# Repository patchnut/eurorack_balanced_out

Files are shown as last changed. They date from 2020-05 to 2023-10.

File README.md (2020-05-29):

# Eurorack Balanced Out
Stereo balanced output board with attenuation for in eurorack cases.

This is a Kicad project for a balanced output board to build in the back of an Eurorack case. This is not a eurorack
module, but instead can be built into a eurorack case to provide two balanced outputs on TRS jacks on the back of the case.
The circuit is powered from a normal +12v/-12v eurorack power supply and can be connected to a module that provides
mini-jack connectors so signals can be patched into the output. The current assumption is that we can use the Doepfer A-139-2 
Headphone Amplifier module for this. It provides mini jack inputs, volume control and has two un-populated headers on the board
that look like they provide outputs.

Features
- Two balanced 6,3 mm TRS jack outputs
- 10 pin eurorack compatible power connector for +12v/-12v
- 1/4 attenuation, use different resistors to change attenuation level
- two THAT1646 output drivers
- inputs on two 2-pin headers for internal connection to front panel module

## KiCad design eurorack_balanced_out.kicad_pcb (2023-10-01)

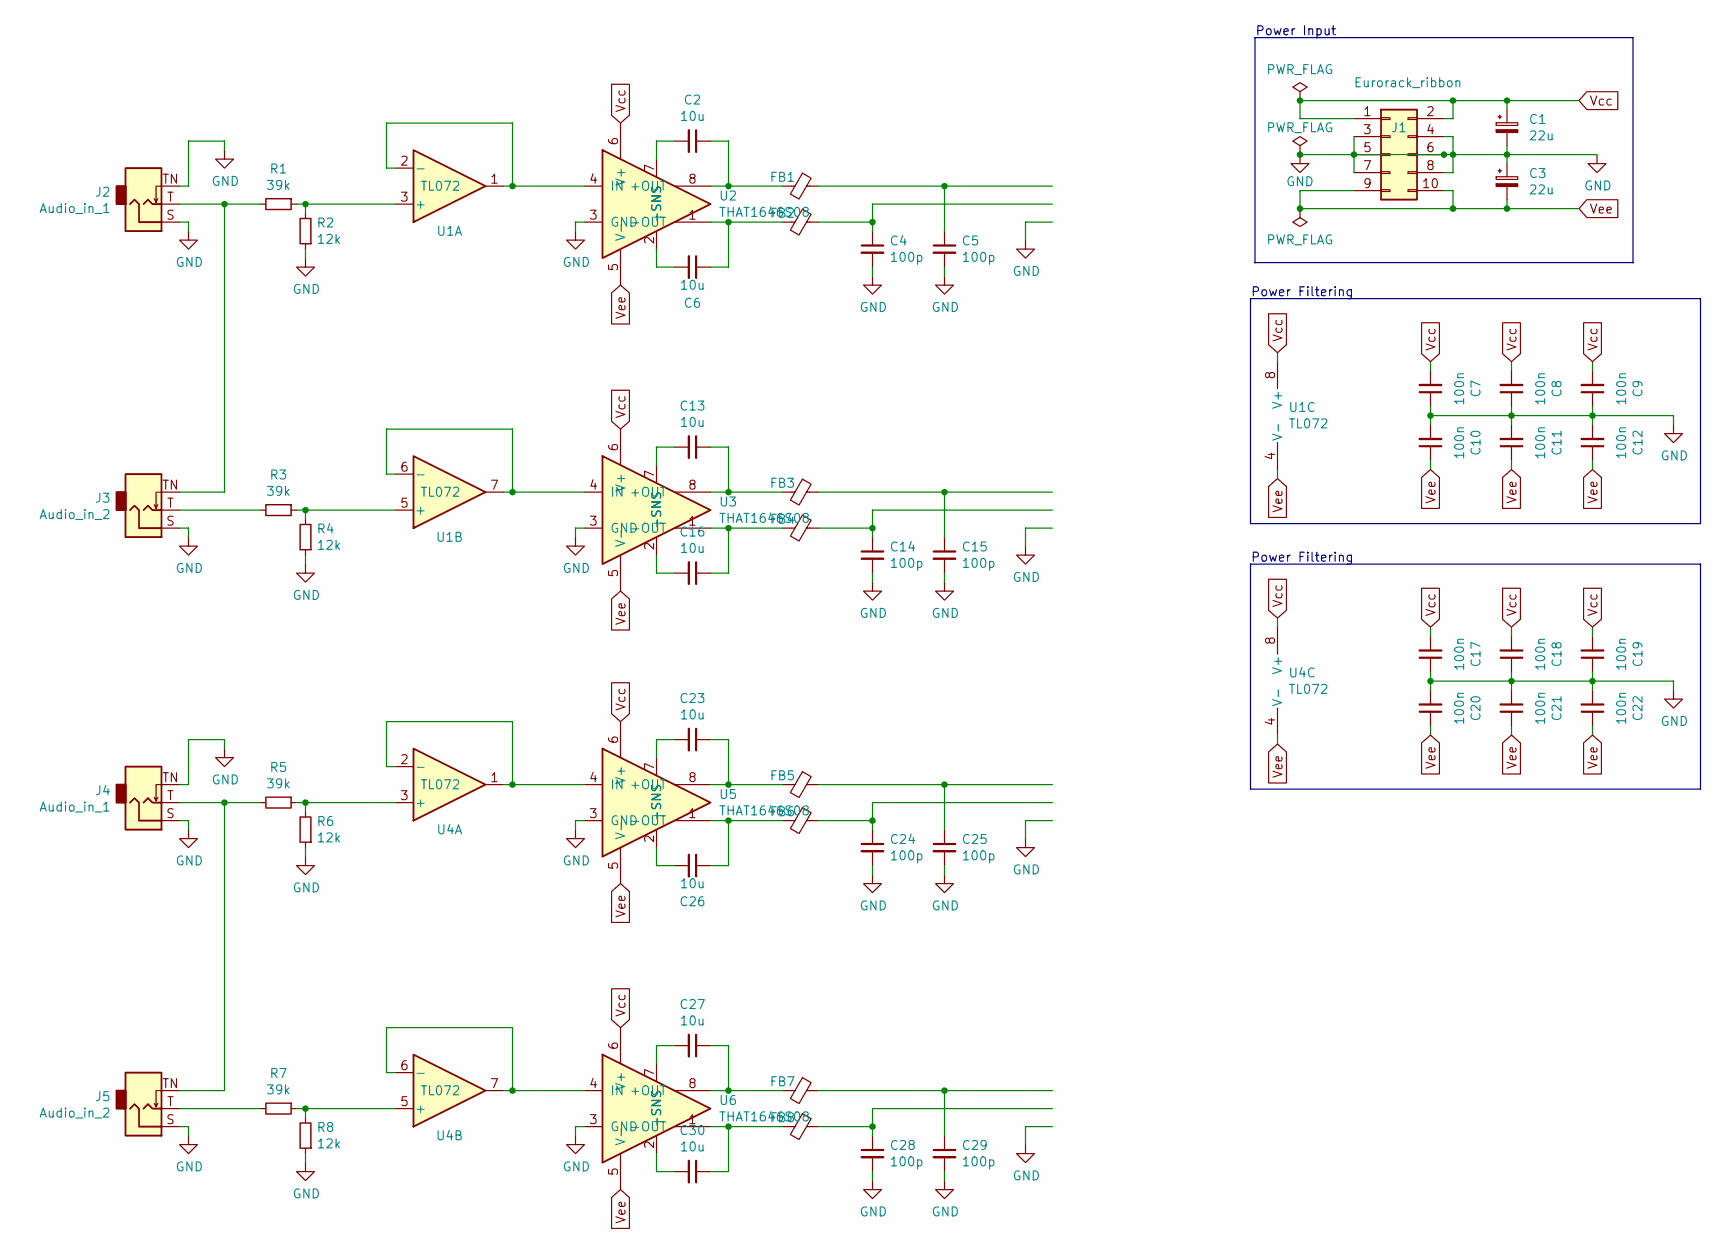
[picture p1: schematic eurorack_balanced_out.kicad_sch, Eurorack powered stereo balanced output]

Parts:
C1, C3: 22u; CP_Elec_6.3x5.4; Mouser 647-UWT1E220MCL1B
C2, C6, C13, C16, C23, C26, C27, C30: 10u; CP_Elec_6.3x5.4; Mouser 647-UWP1E100MCL
C4, C5, C14, C15, C24, C25, C28, C29: 100p; C_0805_2012Metric_Pad1.18x1.45mm_HandSolder; Mouser 80-C0805C101JAGAUTO
C7, C8, C9, C10, C11, C12, C17, C18, C19, C20, C21, C22: 100n; C_0805_2012Metric_Pad1.18x1.45mm_HandSolder; Mouser 80-C0805C104K5RACLR
FB1, FB2, FB3, FB4, FB5, FB6, FB7, FB8: 600R @ 100Mhz; R_0805_2012Metric_Pad1.20x1.40mm_HandSolder; Mouser 81-BLM21A601F
J1: Eurorack_ribbon; PinHeader_2x05_P2.54mm_Vertical; Mouser 200-TSS10501TD
J2, J4: Audio_in_1; Jack_3.5mm_QingPu_WQP-PJ398SM_Vertical_CircularHoles
J3, J5: Audio_in_2; Jack_3.5mm_QingPu_WQP-PJ398SM_Vertical_CircularHoles
R1, R3, R5, R7: 39k; R_0805_2012Metric_Pad1.20x1.40mm_HandSolder; Mouser 667-ERJ-6ENF3901V
R2, R4, R6, R8: 12k; R_0805_2012Metric_Pad1.20x1.40mm_HandSolder; Mouser 667-ERJ-S06F1201V
U1, U4: TL072; SO-8_5.3x6.2mm_P1.27mm
U2, U3, U5, U6: THAT1646S08; SOIC-8_3.9x4.9mm_P1.27mm

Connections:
GND: C1.2, C3.1, C4.2, C5.2, C7.1, C8.1, C9.1, C10.2, C11.2, C12.2, C14.2, C15.2, C17.1, C18.1, C19.1, C20.2, C21.2, C22.2, C24.2, C25.2, C28.2, C29.2, J1.3, J1.4, J1.5, J1.6, J1.7, J1.8, J2.S, J2.TN, J3.S, J4.S, J4.TN, J5.S, R2.1, R4.1, R6.1, R8.1, U2.3 (GND), U3.3 (GND), U5.3 (GND), U6.3 (GND)
unnamed: C4.1, FB2.1
unnamed: C5.1, FB1.1
unnamed: C14.1, FB4.1
unnamed: C15.1, FB3.1
unnamed: C24.1, FB6.1
unnamed: C25.1, FB5.1
unnamed: C28.1, FB8.1
unnamed: C29.1, FB7.1
unnamed: J2.T, J3.TN, R1.2
unnamed: J3.T, R3.2
unnamed: J4.T, J5.TN, R5.2
unnamed: J5.T, R7.2
unnamed: R1.1, R2.2, U1.3 (+)
unnamed: U1.1, U1.2 (-), U2.4 (IN)
unnamed: R3.1, R4.2, U1.5 (+)
unnamed: U1.6 (-), U1.7, U3.4 (IN)
unnamed: C2.1, FB1.2, U2.8 (+OUT)
unnamed: C2.2, U2.7 (+SNS)
unnamed: C6.1, FB2.2, U2.1 (-OUT)
unnamed: C6.2, U2.2 (-SNS)
unnamed: C13.1, FB3.2, U3.8 (+OUT)
unnamed: C13.2, U3.7 (+SNS)
unnamed: C16.1, FB4.2, U3.1 (-OUT)
unnamed: C16.2, U3.2 (-SNS)
unnamed: R5.1, R6.2, U4.3 (+)
unnamed: U4.1, U4.2 (-), U5.4 (IN)
unnamed: R7.1, R8.2, U4.5 (+)
unnamed: U4.6 (-), U4.7, U6.4 (IN)
unnamed: C23.1, FB5.2, U5.8 (+OUT)
unnamed: C23.2, U5.7 (+SNS)
unnamed: C26.1, FB6.2, U5.1 (-OUT)
unnamed: C26.2, U5.2 (-SNS)
unnamed: C27.1, FB7.2, U6.8 (+OUT)
unnamed: C27.2, U6.7 (+SNS)
unnamed: C30.1, FB8.2, U6.1 (-OUT)
unnamed: C30.2, U6.2 (-SNS)
Vcc: C1.1, C7.2, C8.2, C9.2, C17.2, C18.2, C19.2, J1.1, J1.2, U1.8 (V+), U2.6 (V+), U3.6 (V+), U4.8 (V+), U5.6 (V+), U6.6 (V+)
Vee: C3.2, C10.1, C11.1, C12.1, C20.1, C21.1, C22.1, J1.9, J1.10, U1.4 (V-), U2.5 (V-), U3.5 (V-), U4.4 (V-), U5.5 (V-), U6.5 (V-)

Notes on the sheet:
Power Filtering
Power Input

Board: 2 copper layers, 57 parts (0 on the bottom side), 39 nets, no tracks yet.

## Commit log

2020-05-14 init project
    [eurorack_balanced_out.kicad_pcb, eurorack_balanced_out.sch]
2020-05-21 add output drivers for both channels
    [eurorack_balanced_out.sch]
2020-05-21 add eurorack power connector + filtering
    [eurorack_balanced_out.sch]
2020-05-21 add input connectors
    [eurorack_balanced_out.sch]
2020-05-21 add output jacks
    [eurorack_balanced_out.sch]
2020-05-22 add output footprint
    [eurorack_balanced_out.sch]
2020-05-22 delete a channel
    we'll duplicate it again when we're done
    [eurorack_balanced_out.sch]
2020-05-22 add output protection diodes
    [eurorack_balanced_out.sch]
2020-05-22 output emc filtering
    [eurorack_balanced_out.sch]
2020-05-22 re-add second channel
    [eurorack_balanced_out.sch]
2020-05-22 annotate components
    [eurorack_balanced_out.sch]
2020-05-22 fix erc errors
    [eurorack_balanced_out.sch]
2020-05-23 replace 1n4004 output protection diodes with BAV99
    [eurorack_balanced_out.sch]
2020-05-23 replace resistor symbols with R small
    [eurorack_balanced_out.sch]
2020-05-23 replace capacitors with small versions
    [eurorack_balanced_out.sch]
2020-05-23 add pinheader footprints
    [eurorack_balanced_out.sch]
2020-05-23 fix protection diode orientation
    [eurorack_balanced_out.sch]
2020-05-23 fix weird erc non connected error
    [eurorack_balanced_out.sch]
2020-05-24 fix power connector footprint
    [eurorack_balanced_out.sch]
2020-05-24 start pcb layout
    [eurorack_balanced_out.kicad_pcb]
2020-05-24 rought first placement
    [eurorack_balanced_out.kicad_pcb]
2020-05-26 try to make placement a bit more compact
    [eurorack_balanced_out.kicad_pcb]
2020-05-26 save some more board space
    [eurorack_balanced_out.kicad_pcb]
2020-05-27 clean up component placement
    [eurorack_balanced_out.kicad_pcb]
2020-05-27 clean up edgecut
    [eurorack_balanced_out.kicad_pcb]
2020-05-27 route signals and some power
    [eurorack_balanced_out.kicad_pcb]
2020-05-27 prepare for power routing and cleanup
    [eurorack_balanced_out.kicad_pcb]
2020-05-27 fix ground planes
    [eurorack_balanced_out.kicad_pcb]
2020-05-27 more cleanup
    [eurorack_balanced_out.kicad_pcb]
2020-05-27 left channel power routing
    [eurorack_balanced_out.kicad_pcb]
2020-05-28 rout rest of power
    [eurorack_balanced_out.kicad_pcb]
2020-05-28 small track cleanup
    [eurorack_balanced_out.kicad_pcb]
2020-05-28 fix silkscreen
    [eurorack_balanced_out.kicad_pcb]
2020-05-29 add some mouser part numbers
    [eurorack_balanced_out.sch]
2020-05-29 fix some resistor values
    [eurorack_balanced_out.sch]
2020-05-29 finish mouser part numbers
    [eurorack_balanced_out.sch]
2020-05-29 use different footprint for 10uF cap so we can use the 25V version
    [eurorack_balanced_out.kicad_pcb, eurorack_balanced_out.sch]
2020-05-29 change mouser part number for 10u non polarized caps to 25v version
    [eurorack_balanced_out.sch]
2020-05-30 set revision number in schematic
    [eurorack_balanced_out.sch]
2020-05-30 set pcb page settins
    [eurorack_balanced_out.kicad_pcb]
2020-05-30 fix fills and edge cuts to new board size
    [eurorack_balanced_out.kicad_pcb]
2020-05-30 prepare room for decoupling caps
    [eurorack_balanced_out.kicad_pcb]
2020-05-30 fix decoupling caps in schematic
    [eurorack_balanced_out.sch]
2020-05-31 fixed lost piece of silkscreen text
    [eurorack_balanced_out.kicad_pcb]
2020-05-31 fix missing connections
    [eurorack_balanced_out.sch]
2020-05-31 place decoupling caps
    [eurorack_balanced_out.kicad_pcb]
2020-05-31 optimize channel input placement
    [eurorack_balanced_out.kicad_pcb]
2020-05-31 removed plus from non-polarized elco footprints
    [eurorack_balanced_out.kicad_pcb]
2020-05-31 fix silkscreen so it doesnt change back again
    [eurorack_balanced_out.kicad_pcb]
2020-05-31 route signals
    [eurorack_balanced_out.kicad_pcb]
2020-05-31 finish routing
    [eurorack_balanced_out.kicad_pcb]
2020-05-31 edgecut rounded corners
    [eurorack_balanced_out.kicad_pcb]
2020-05-31 re-fill before export and ordering
    [eurorack_balanced_out.kicad_pcb]
2020-06-05 add revision to silkscreen
    [eurorack_balanced_out.kicad_pcb]
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2020-06-11 define track with for power netclass
    [eurorack_balanced_out.kicad_pcb]
2020-06-11 rotate power connector and capacitors
    [eurorack_balanced_out.kicad_pcb]
2020-06-11 fix silkscreen for power connector orientation
    [eurorack_balanced_out.kicad_pcb]
2020-06-11 re-route power (again)
    [eurorack_balanced_out.kicad_pcb]
2020-06-11 rotated input capacitors to improve ground continuity
    [eurorack_balanced_out.kicad_pcb]
2020-06-26 add measurements
    [eurorack_balanced_out.kicad_pcb]
2020-07-07 revision 0.1.1
    [eurorack_balanced_out.kicad_pcb, eurorack_balanced_out.sch]
2021-04-29 update schematic, add input buffer
    [eurorack_balanced_out.kicad_pcb, eurorack_balanced_out.sch]
2021-04-29 increase input impedance
    [eurorack_balanced_out.kicad_pcb, eurorack_balanced_out.sch]
2021-04-29 set input and output jacks
    [eurorack_balanced_out.kicad_pcb, eurorack_balanced_out.sch]
2021-05-05 Cleanup of Schematic
    Separated input and output clamps
    Improved formatting
    [eurorack_balanced_out.sch]
2021-05-09 fix typo in THAT1646 symbol reference
    [eurorack_balanced_out.sch]
2021-05-09 use thonkycon TRS footprint for outputs
    [eurorack_balanced_out.kicad_pcb, eurorack_balanced_out.sch]
2021-05-09 add board outline and move components out of the way
    [eurorack_balanced_out.kicad_pcb]
2021-05-09 roughly place components
    [eurorack_balanced_out.kicad_pcb]
2021-05-09 flip chips to back of the board
    [eurorack_balanced_out.kicad_pcb]
2021-05-09 add ground planes
    [eurorack_balanced_out.kicad_pcb]
2021-05-09 fix connector placement
    [eurorack_balanced_out.kicad_pcb]
2021-05-09 rough place output filtering
    [eurorack_balanced_out.kicad_pcb]
2021-05-09 group power filtering caps with chips
    [eurorack_balanced_out.kicad_pcb]
2021-05-11 route some stuff
    [eurorack_balanced_out.kicad_pcb]
2021-05-12 remove clamps from schematic
    [eurorack_balanced_out.sch]
2021-05-12 re-layout pcb make room for power header layout the board so left->right = top->bottom remove clamp diodes everything on one side
    [eurorack_balanced_out.kicad_pcb]
2023-04-03 make schematic 4 channel
    remove output jacks
    clean up layout
    [eurorack_balanced_out.kicad_sch]
2023-10-01 update buffer to ne5532
    [eurorack_balanced_out.kicad_pcb]
